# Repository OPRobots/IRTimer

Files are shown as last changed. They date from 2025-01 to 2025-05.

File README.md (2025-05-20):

# IRTimer: Maze & Line StopWatch
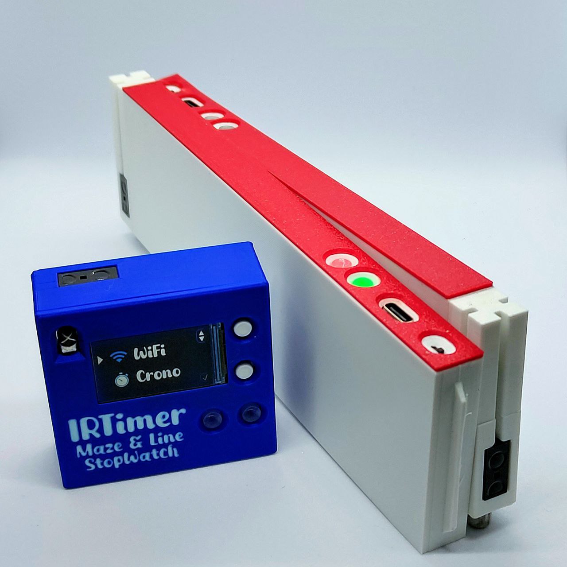
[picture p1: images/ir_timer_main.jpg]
IRTimer IRTimer - Maze & Line StopWatch

Cronómetro para MicroMouse y LineFollower con conectividad WiFi para visualización de interfaz gráfica web, permitiendo una simple integración con OBS y softwares similares. Además, tambien posee integración con nuestro sistema de inicio de robots [IRStart](https://github.com/OPRobots/IRStart), desde el cual se podrá detener y reiniciar el cronómetro a distancia.

## Módulo Principal y cronómetro de LineFollower
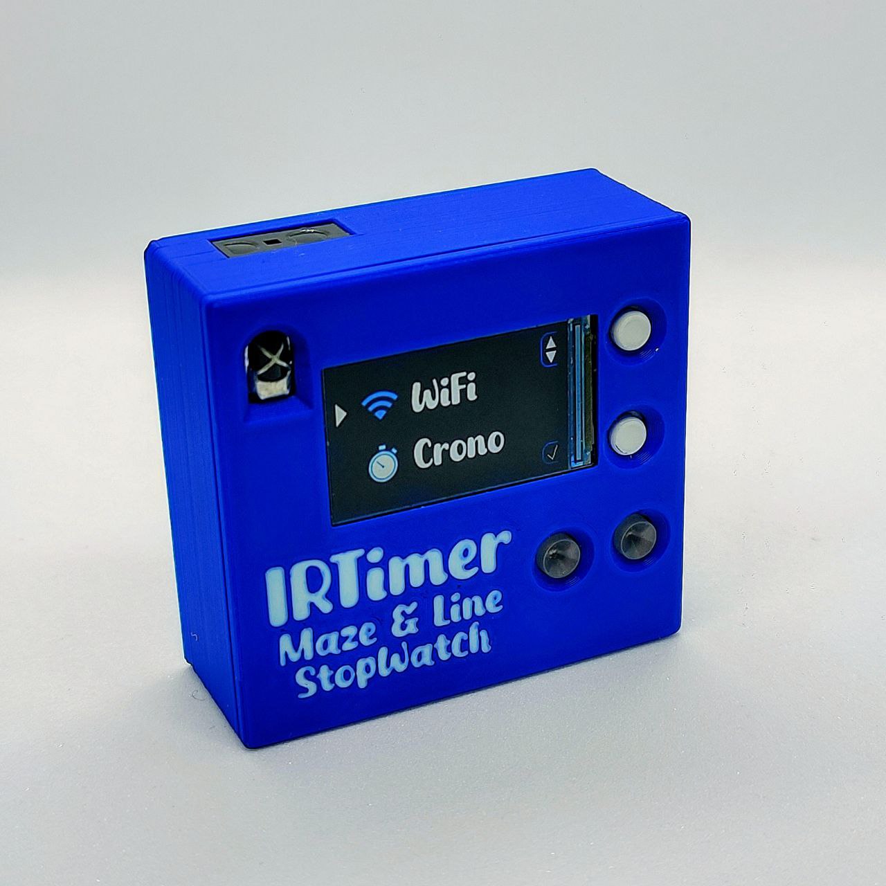
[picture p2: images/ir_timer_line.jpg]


El módulo principal está pensado para situarse cerca de la línea del circuito para detectar el paso de los robots detectando su paso a través de un sensor infrarojo situado en la parte posterior del mismo.

Este módulo es el encargado de conectarse a la red WiFi local y montar un servidor web para la visualización de cronos en tiempo real. Este servidor web está pensado para poder integrarse de forma simple a modo de overlay en programas de streaming como OBS Studio para mostrar de forma más dinamica a la audiencia los tiempos de los robots. También será el encargado de recibir los comandos de inicio y parada desde los módulos de laberinto mediante ESP-NOW.

### Hardware
- **Microcontrolador**: ESP32-C3 supermini
- **Pantalla**: LCD de 135x240 RGB TFT (ST7789)
- **Sensor**: Sharp GP2Y0D815Z0F (15cm)
- **Receptor IR 38kHz**: TSSP77038TR
- **LEDs**: 2x LEDs RGB (WS2812B)
- **LiPo**: Batería 1S 1500mAh 523450

## Módulo MicroMouse
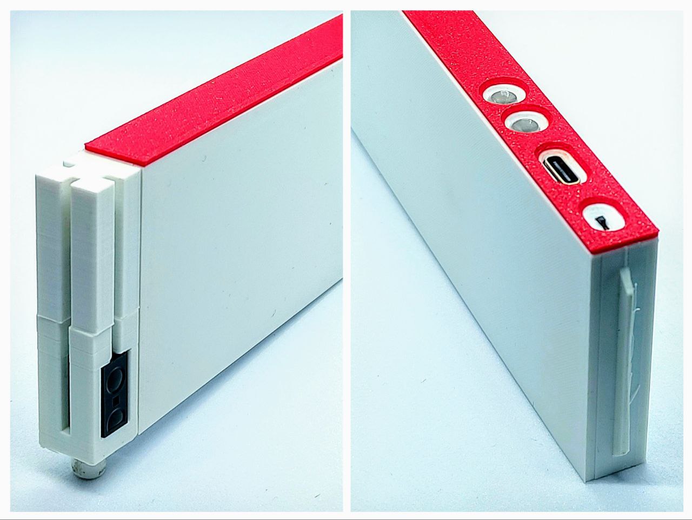
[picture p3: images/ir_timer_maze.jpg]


Estos módulos tienen un hardware muy similar al módulo principal, salvo porque no tienen botones ni pantalla. En este caso, el sensor está embebido dentro del propio poste para interferir lo mínimo posible con las lecturas del robot. Además, el diseño del poste permite multitud de colocaciones para facilitar el montaje en el laberinto.

Las paredes se comunican mediante ESP-NOW con el módulo principal enviando los comandos de START y STOP del cronómetro. Una vez la pared de inicio ha dado la señal, se queda inactiva hasta que se mantenga el sensor detectando por unos segundos para evitar que se inicie una nueva vuelta si el robot vuelve a la casilla inicial (sobre todo en reconocimiento).

### Hardware
- **Microcontrolador**: ESP32-C3 supermini
- **Sensor**: Sharp GP2Y0D815Z0F (15cm)
- **LEDs**: 2x LEDs RGB (WS2812B)
- **LiPo**: Batería 1S 1500mAh 523450

## PCB
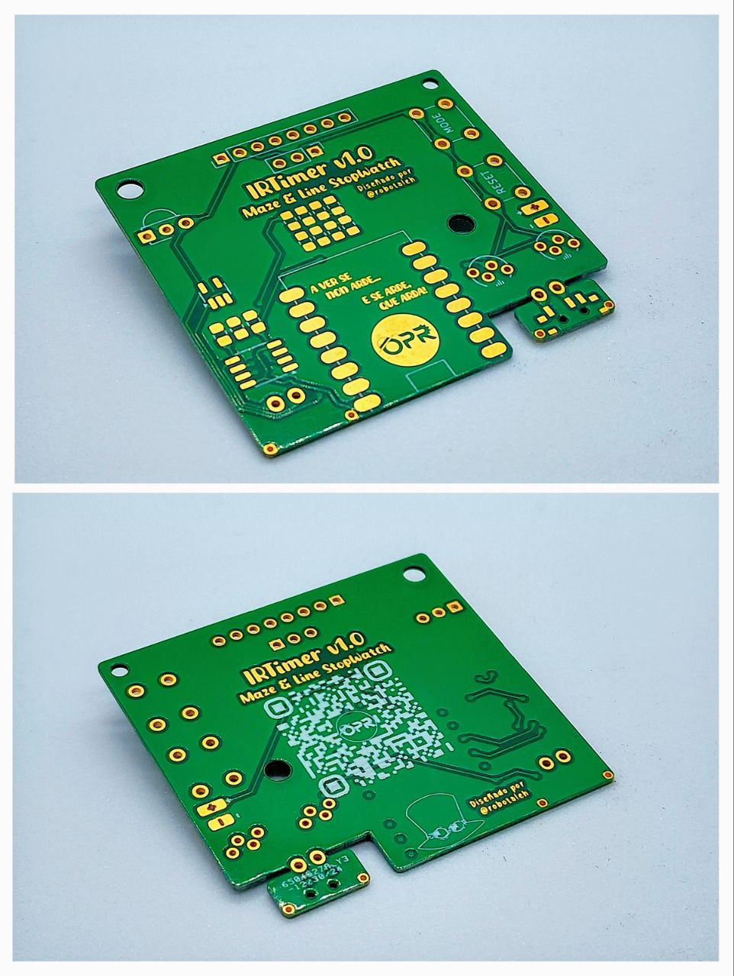
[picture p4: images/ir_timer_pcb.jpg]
IRTimer IRTimer - PCB


Tiene un tamaño muy reducido, menos de 50x50mm, que permite encargarse en los principales fabricantes de PCB con acabado en Oro para más alucinancia. Además, también tiene un total de 6 capas, siendo la primera PCB de OPRobots en tener más de 2 capas.

Contiene los componentes necesarios para cargar la LiPo mediante el conector USB-C del propio ESP32, además de un lector de batería para avisar en caso de que la batería esté baja. Permite la conexión de los RGB tanto en vertical para el módulo principal como en horizontal para los módulos de laberinto.

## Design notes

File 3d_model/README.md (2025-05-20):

# IRTimer: Maze & Line StopWatch
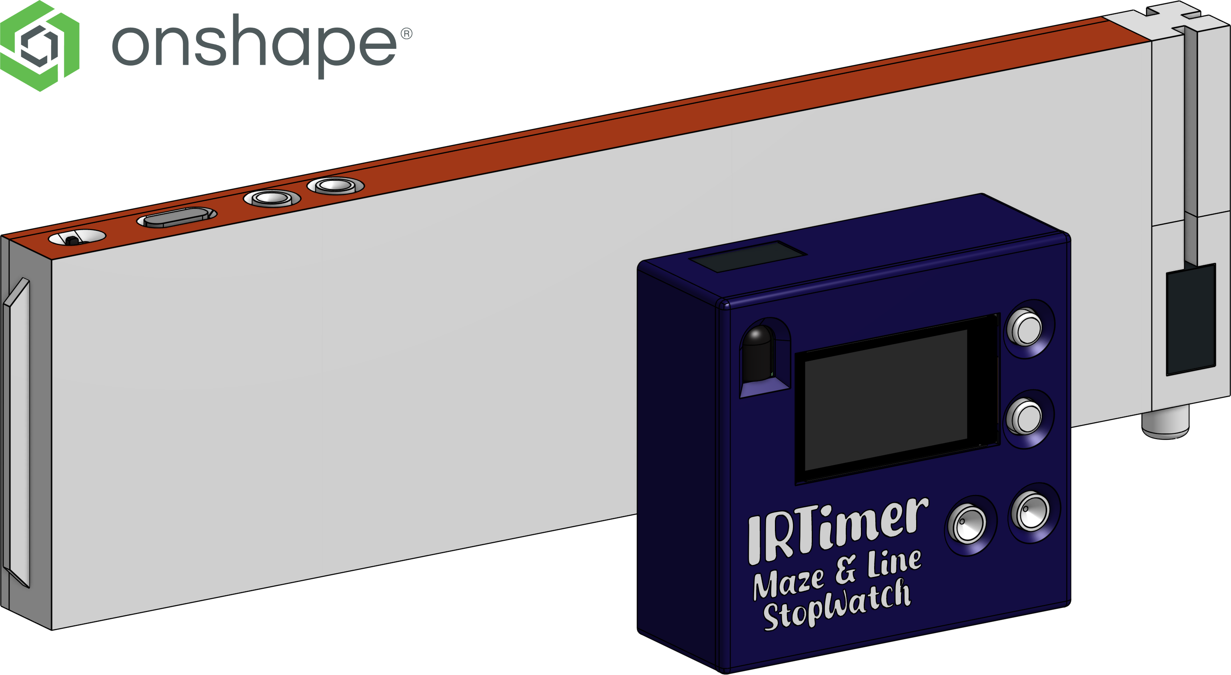
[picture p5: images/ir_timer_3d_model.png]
IRTimer IRTimer - Maze & Line StopWatch (https://cad.onshape.com/documents/0bb3dbbb5141aa9193bcd839/w/e93c359765e08a92c0bd40fe/e/a3bf6be277aa9cb775474855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)

El diseño de IRTimer se encuentra disponible en [Onshape](https://cad.onshape.com/documents/0bb3dbbb5141aa9193bcd839/w/e93c359765e08a92c0bd40fe/e/a3bf6be277aa9cb775474855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), donde se puede ver el modelo 3D y descargar los archivos STL para impresión 3D. El modelo incluye tanto el módulo principal como los módulos de laberinto, además de la PCB y el soporte para la pantalla.

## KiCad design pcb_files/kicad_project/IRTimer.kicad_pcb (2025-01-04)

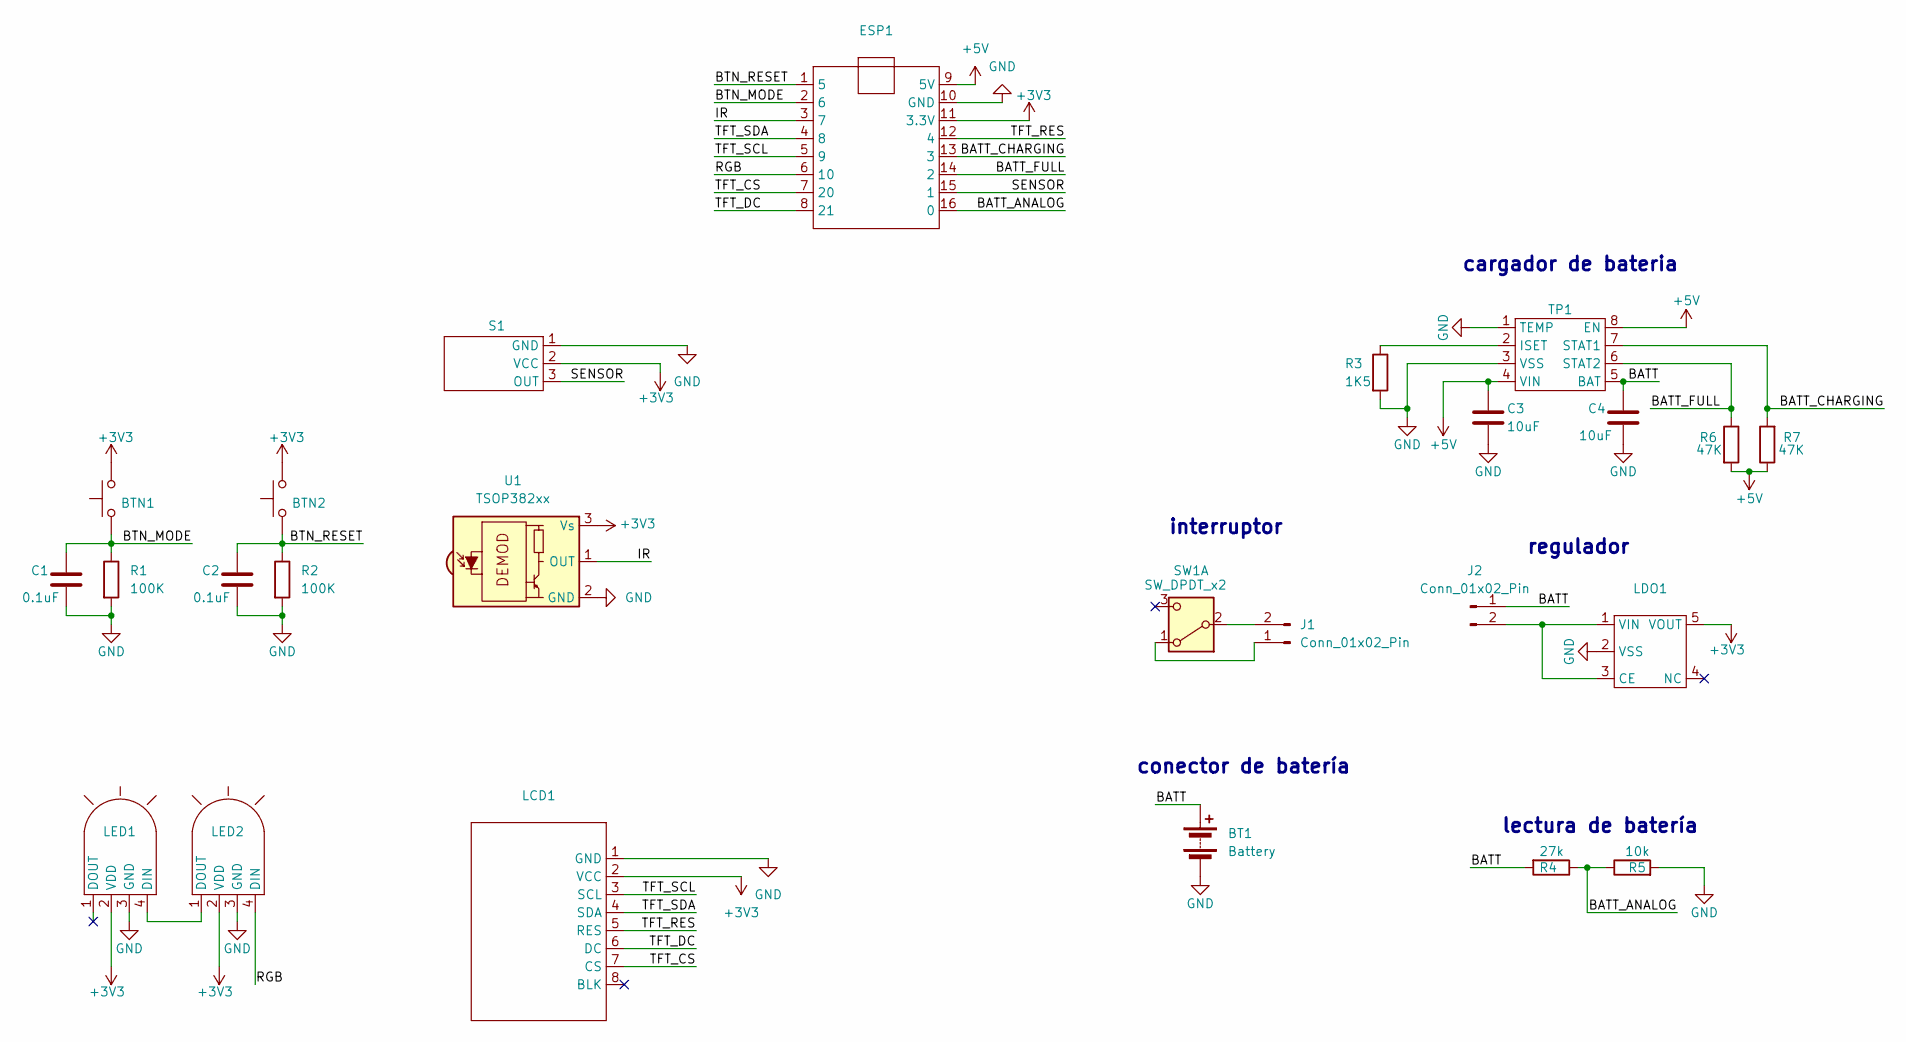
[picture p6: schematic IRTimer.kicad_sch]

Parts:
BT1: Battery; Leds_IR_Remote
BTN1, BTN2: SW_PUSH_6mm_H8mm
C1, C2: 0.1uF; C_0805_2012Metric_Pad1.18x1.45mm_HandSolder
C3, C4: 10uF; C_0805_2012Metric_Pad1.18x1.45mm_HandSolder
ESP1: ESP32_supermini
J1, J2: Conn_01x02_Pin; PinHeader_1x02_P2.54mm_Vertical
LCD1: ST7789V_LCD_RGB_135x240
LDO1: SOT-23-5_HandSoldering
LED1, LED2: LED_D5.0mm-4_RGB_Staggered_Pins
R1, R2: 100K; R_0805_2012Metric_Pad1.20x1.40mm_HandSolder
R3: 1K5; R_0805_2012Metric_Pad1.20x1.40mm_HandSolder
R4: 27k; R_0805_2012Metric_Pad1.20x1.40mm_HandSolder
R5: 10k; R_0805_2012Metric_Pad1.20x1.40mm_HandSolder
R6, R7: 47K; R_0805_2012Metric_Pad1.20x1.40mm_HandSolder
S1: PinHeader_1x03_P2.54mm_Vertical
SW1: SW_DPDT_x2; SW_SPDT_PCM12
TP1: SOP-8_3.9x4.9mm_P1.27mm
U1: TSOP382xx; IR TSOP38238 90º

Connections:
+3V3: BTN1.2, BTN2.2, ESP1.11 (3.3V), LCD1.2 (VCC), LDO1.5 (VOUT), LED1.2 (VDD), LED2.2 (VDD), S1.2 (VCC), U1.3 (Vs); also elsewhere on the board
+5V: C3.1, ESP1.9 (5V), R6.2, R7.1, TP1.4 (VIN), TP1.8 (EN)
/BATT: BT1.1 (+), C4.1, J2.1, R4.2, TP1.5 (BAT)
/BATT_ANALOG: ESP1.16 (0), R4.1, R5.1
/BATT_CHARGING: ESP1.13 (3), R7.2, TP1.7 (STAT1)
/BATT_FULL: ESP1.14 (2), R6.1, TP1.6 (STAT2)
/BTN_MODE: BTN1.1, C1.1, ESP1.2 (6), R1.1; also elsewhere on the board
/BTN_RESET: BTN2.1, C2.1, ESP1.1 (5), R2.1; also elsewhere on the board
/IR: ESP1.3 (7), U1.1 (OUT)
/RGB: ESP1.6 (10), LED2.4 (DIN)
/SENSOR: ESP1.15 (1), S1.3 (OUT)
/TFT_CS: ESP1.7 (20), LCD1.7 (CS)
/TFT_DC: ESP1.8 (21), LCD1.6 (DC)
/TFT_RES: ESP1.12 (4), LCD1.5 (RES)
/TFT_SCL: ESP1.5 (9), LCD1.3 (SCL)
/TFT_SDA: ESP1.4 (8), LCD1.4 (SDA)
GND: BT1.2 (-), C1.2, C2.2, C3.2, C4.2, ESP1.10 (GND), LCD1.1 (GND), LDO1.2 (VSS), LED1.3 (GND), LED2.3 (GND), R1.2, R2.2, R3.2, R5.2, S1.1 (GND), TP1.1 (TEMP), TP1.3 (VSS), U1.2 (GND)
unnamed: J1.1, SW1.1 (A)
unnamed: J1.2, SW1.2 (B)
unnamed: J2.2, LDO1.1 (VIN), LDO1.3 (CE)
unnamed: LED1.4 (DIN), LED2.1 (DOUT)
unnamed: R3.1, TP1.2 (ISET)

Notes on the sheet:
cargador de bateria
conector de batería
regulador
interruptor
lectura de batería

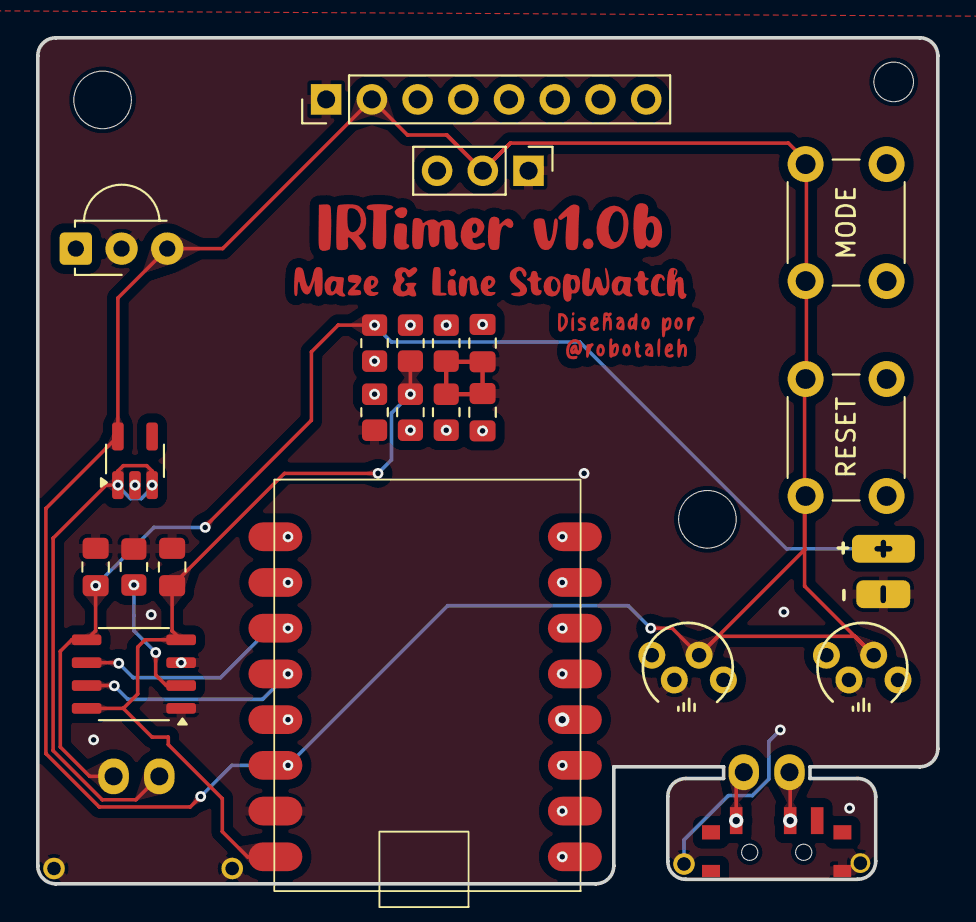
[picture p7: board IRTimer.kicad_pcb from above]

Board: 6 copper layers, 50.0 x 47.0 mm, 25 parts (0 on the bottom side), 22 nets.

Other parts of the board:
MODE: SW_PUSH_6mm_H8mm
RESET: SW_PUSH_6mm_H8mm

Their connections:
+3V3: MODE.2, RESET.2; also elsewhere on the board
/BTN_MODE: MODE.1; also elsewhere on the board
/BTN_RESET: RESET.1; also elsewhere on the board

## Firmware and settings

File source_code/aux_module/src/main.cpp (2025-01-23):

#include <Arduino.h>

#include "client.h"
#include "config.h"
#include "stopwatch.h"

void setup() {
  config_setup();
  delay(500);
  set_led(RGB_CONNECTION, 0, 0, 0);
  delay(500);
  switch (config_get_wall()) {
    case WALL_START:
      set_led(RGB_CONNECTION, 0, 10, 0);
      break;
    case WALL_FINISH:
      set_led(RGB_CONNECTION, 10, 0, 0);
      break;
  }
}

void loop() {
  stopwatch_check();
  manage_battery();
}

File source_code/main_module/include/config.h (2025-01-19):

#ifndef CONFIG_H
#define CONFIG_H

#include "rc5.h"
#include "screen.h"
#include "web.h"
#include <Arduino.h>

#define IR_PIN 7
#define SENSOR_PIN 1
#define NEOPIXEL_PIN 10

#define BTN_TOP_PIN 6
#define BTN_BOTTOM_PIN 5

#define BATT_CHARGING_PIN 3
#define BATT_FULL_PIN 2
#define BATT_VOLTAGE_PIN 0

#define TFT_MOSI 8 // SDA Pin on ESP32
#define TFT_SCLK 9 // SCL Pin on ESP32
#define TFT_CS 20  // Chip select control pin
#define TFT_DC 21  // Data Command control pin
#define TFT_RST 4  // Reset pin (could connect to RST pin)

void config_setup();

#endif

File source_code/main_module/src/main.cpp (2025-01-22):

#include "config.h"
#include "control.h"
#include "rc5.h"
#include "screen.h"
#include "utils.h"
#include "web.h"
#include <Arduino.h>


void setup() {
  config_setup();
  control_init();
}

void loop() {
  // rc5_update();
  // stopwatch_check();
  control_manage_screen();
  control_manage_battery();
  control_manage_pending_event();
}

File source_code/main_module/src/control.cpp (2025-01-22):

#include "control.h"

static enum SCREENS current_screen = SCREEN_SPLASH;
static uint32_t current_screen_ms = 0;

static uint8_t menu_index = 0;

static uint32_t battey_blink_ms = 0;
static bool battery_blink_state = false;

static enum RC5_EVENTS pending_event = EVENT_NONE;

static void set_screen(enum SCREENS screen) {
  current_screen = screen;
  current_screen_ms = millis();
  switch (screen) {
    case SCREEN_SPLASH:
      screen_show_splash();
      break;
    case SCREEN_MENU:
      screen_show_menu();
      screen_set_button_icon(BUTTON_TOP_RIGHT, ICON_UP_DOWN);
      screen_set_button_icon(BUTTON_BOTTOM_RIGHT, ICON_CHECK);
      menu_index = 0;
      screen_set_side_selector(menu_index, 2);
      break;
    case SCREEN_WIFI_INIT:
      screen_show_wifi_init();
      if (web_setup()) {
        set_screen(SCREEN_WIFI_INFO);
      } else {
        set_screen(SCREEN_WIFI_FAIL);
      }
      break;
    case SCREEN_WIFI_INFO:
      screen_show_wifi_info();
      screen_set_button_text(BUTTON_BOTTOM_RIGHT, "MENU");
      break;
    case SCREEN_WIFI_FAIL:
      screen_show_wifi_fail();
      screen_set_button_text(BUTTON_BOTTOM_RIGHT, "MENU");
      break;
    case SCREEN_TIMER:
      screen_show_timer();
      screen_set_button_text(BUTTON_TOP_RIGHT, "RST");
      screen_set_button_text(BUTTON_BOTTOM_RIGHT, "MENU");
      break;
    default:
      screen_show_unknown();
      break;
  }
}

void control_init() {
  set_screen(SCREEN_SPLASH);
}

void control_manage_screen() {
  switch (current_screen) {
    case SCREEN_SPLASH:
      if (millis() - current_screen_ms > 2000) {
        set_screen(SCREEN_MENU);
      }
      break;
    case SCREEN_MENU:
      if (digitalRead(BTN_TOP_PIN)) {
        menu_index = (menu_index + 1) % 2;
        screen_set_side_selector(menu_index, 2);
        while (digitalRead(BTN_TOP_PIN)) {
        }
      }
      if (digitalRead(BTN_BOTTOM_PIN)) {
        switch (menu_index) {
          case 0:
            set_screen(SCREEN_WIFI_INIT);
            break;
          case 1:
            set_screen(SCREEN_TIMER);
            break;
        }
        while (digitalRead(BTN_BOTTOM_PIN)) {
        }
      }
      break;
    case SCREEN_WIFI_INFO:
    case SCREEN_WIFI_FAIL:
      if (digitalRead(BTN_BOTTOM_PIN)) {
        stopwatch_reset();
        set_screen(SCREEN_MENU);
        while (digitalRead(BTN_BOTTOM_PIN)) {
        }
      }
      break;
    case SCREEN_TIMER:
      stopwatch_check();
      if (digitalRead(BTN_TOP_PIN)) {
        stopwatch_reset();
        while (digitalRead(BTN_TOP_PIN)) {
        }
      }
      if (digitalRead(BTN_BOTTOM_PIN)) {
        stopwatch_reset();
        set_screen(SCREEN_MENU);
        while (digitalRead(BTN_BOTTOM_PIN)) {
        }
      }
      break;
  }
}

void control_manage_battery() {
  if (!digitalRead(BATT_CHARGING_PIN)) {
    set_led(RGB_POWER, 50, 0, 0);
  } else if (!digitalRead(BATT_FULL_PIN)) {
    set_led(RGB_POWER, 0, 50, 0);
  } else if (get_battery_voltage() < 3.5) {
    if (millis() - battey_blink_ms > 500) {
      battery_blink_state = !battery_blink_state;
      set_led(RGB_POWER, battery_blink_state ? 50 : 0, 0, 0);
      battey_blink_ms = millis();
    }
  } else {
    set_led(RGB_POWER, 0, 0, 0);
  }
}

void control_manage_pending_event() {
  switch (pending_event) {
    case EVENT_RESET:
      stopwatch_reset();
      break;
    case EVENT_STOP:
      stopwatch_stop();
      break;
  }
  pending_event = EVENT_NONE;
}

void control_set_pending_event(enum RC5_EVENTS event) {
  pending_event = event;
}

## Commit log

2025-01-04 Añade v1.0 de la PCB
    [IRTimer.kicad_pcb, IRTimer.kicad_sch]
2025-01-04 Corrige gambada en el routeo de SCL y SDA de la TFT
    [IRTimer.kicad_pcb, IRTimer.kicad_sch]
2025-01-04 Añade template básica de cronómetro y splash screen
2025-01-05 Optimiza el mostrado del splash screen
2025-01-05 Añade visualización funcional de tiempos mediante TFT
2025-01-05 Añade lectura de botones
2025-01-06 Añade BOM de la PCB
2025-01-06 Inicia gestión de múltiple pantalla y modos
2025-01-15 Añade librarías y funciones básicas de Leds RGB
2025-01-15 Corrige velocidad de SPI de la TFT
2025-01-18 Añade lectura de batería y estado de la carga a main_module
2025-01-18 Corrige texto del botón de control_manage_screen
    [control.cpp]
2025-01-19 Añade imagen de menú y cambio de pantallas
2025-01-19 Mejora el inicio y el menú de WiFi
2025-01-20 Muestra a toda pantalla el último tiempo de vuelta
2025-01-23 Añade gestión completa a los módulos auxiliares · Detección de pared mediante MAC · Envío de comandos de start y finish en función de la pared · Gestión de batería · Control de repetición de start
2025-01-23 Añade gestión de comandos de start y finish en el módulo principal
2025-01-23 Mejora la pantalla de tiempos y corrige bugs visuales
2025-05-13 Añade redundancia de los envíos desde el client.cpp
2025-05-13 Deshabilita el sensor del módulo principal una vez se recibiese algún comando desde los auxiliares
2025-05-20 Añade README de 3d_model
